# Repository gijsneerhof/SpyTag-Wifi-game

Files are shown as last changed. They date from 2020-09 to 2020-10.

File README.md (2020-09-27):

# WIFI Spy Tag game

Hey there, this is the code used for the WIFI based hide and seek/tag game using ESP8266 devices.
The idea behind the game is that humans go and hide, while two zombies (or agents) start seeking them out.
once a zombie comes in proximity to a human, they turn into zombies themselves. Eventually this game will
be rebranded to a spy type of game, with more powerups and features to play around with.

This project is currently in basic WIP shape, if you would like to burn and test out this project however,
more info can be found here for how to accomplish this: https://github.com/con-f-use/esp82XX-basic

## Hardware

Coming soon!

## Instructions

### Installation

Espressif IDF toolchain

### Usage

The function `user_init()` in `user/user_main.c` will be run first. 

### Building

First do `make erase`, then `make initdefault #init3v3` to set the flash correctly.
Lastly, use `make burn` to upload to the ESP8266 controller over `/dev/ttyUSB0`

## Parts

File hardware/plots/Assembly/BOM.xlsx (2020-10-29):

Designator | Comment | Footprint
C1, C2, C3, C4, C5, C6, C7, C8, C9, C10, C11, C12, C13, C14, C15, C16, C17 | 100nF | C_0603_1608Metric
C18, C19 | 10uF | C_0603_1608Metric
R1, R2, R3, R4, R5 | 10K | R_0603_1608Metric
D1, D2, D3, D4, D5, D6, D7, D8, D9, D10, D11, D12, D13, D14, D15, D16 | WS2812B | LED_WS2812B_PLCC4_5.0x5.0mm_P3.2mm
U1 | ESP-12E | ESP-12E_SMD
SW3 | SW_DPDT_x2 | SW_E-Switch_EG1271_DPDT
SW1 | ZOMBIE | SW_PUSH_6mm

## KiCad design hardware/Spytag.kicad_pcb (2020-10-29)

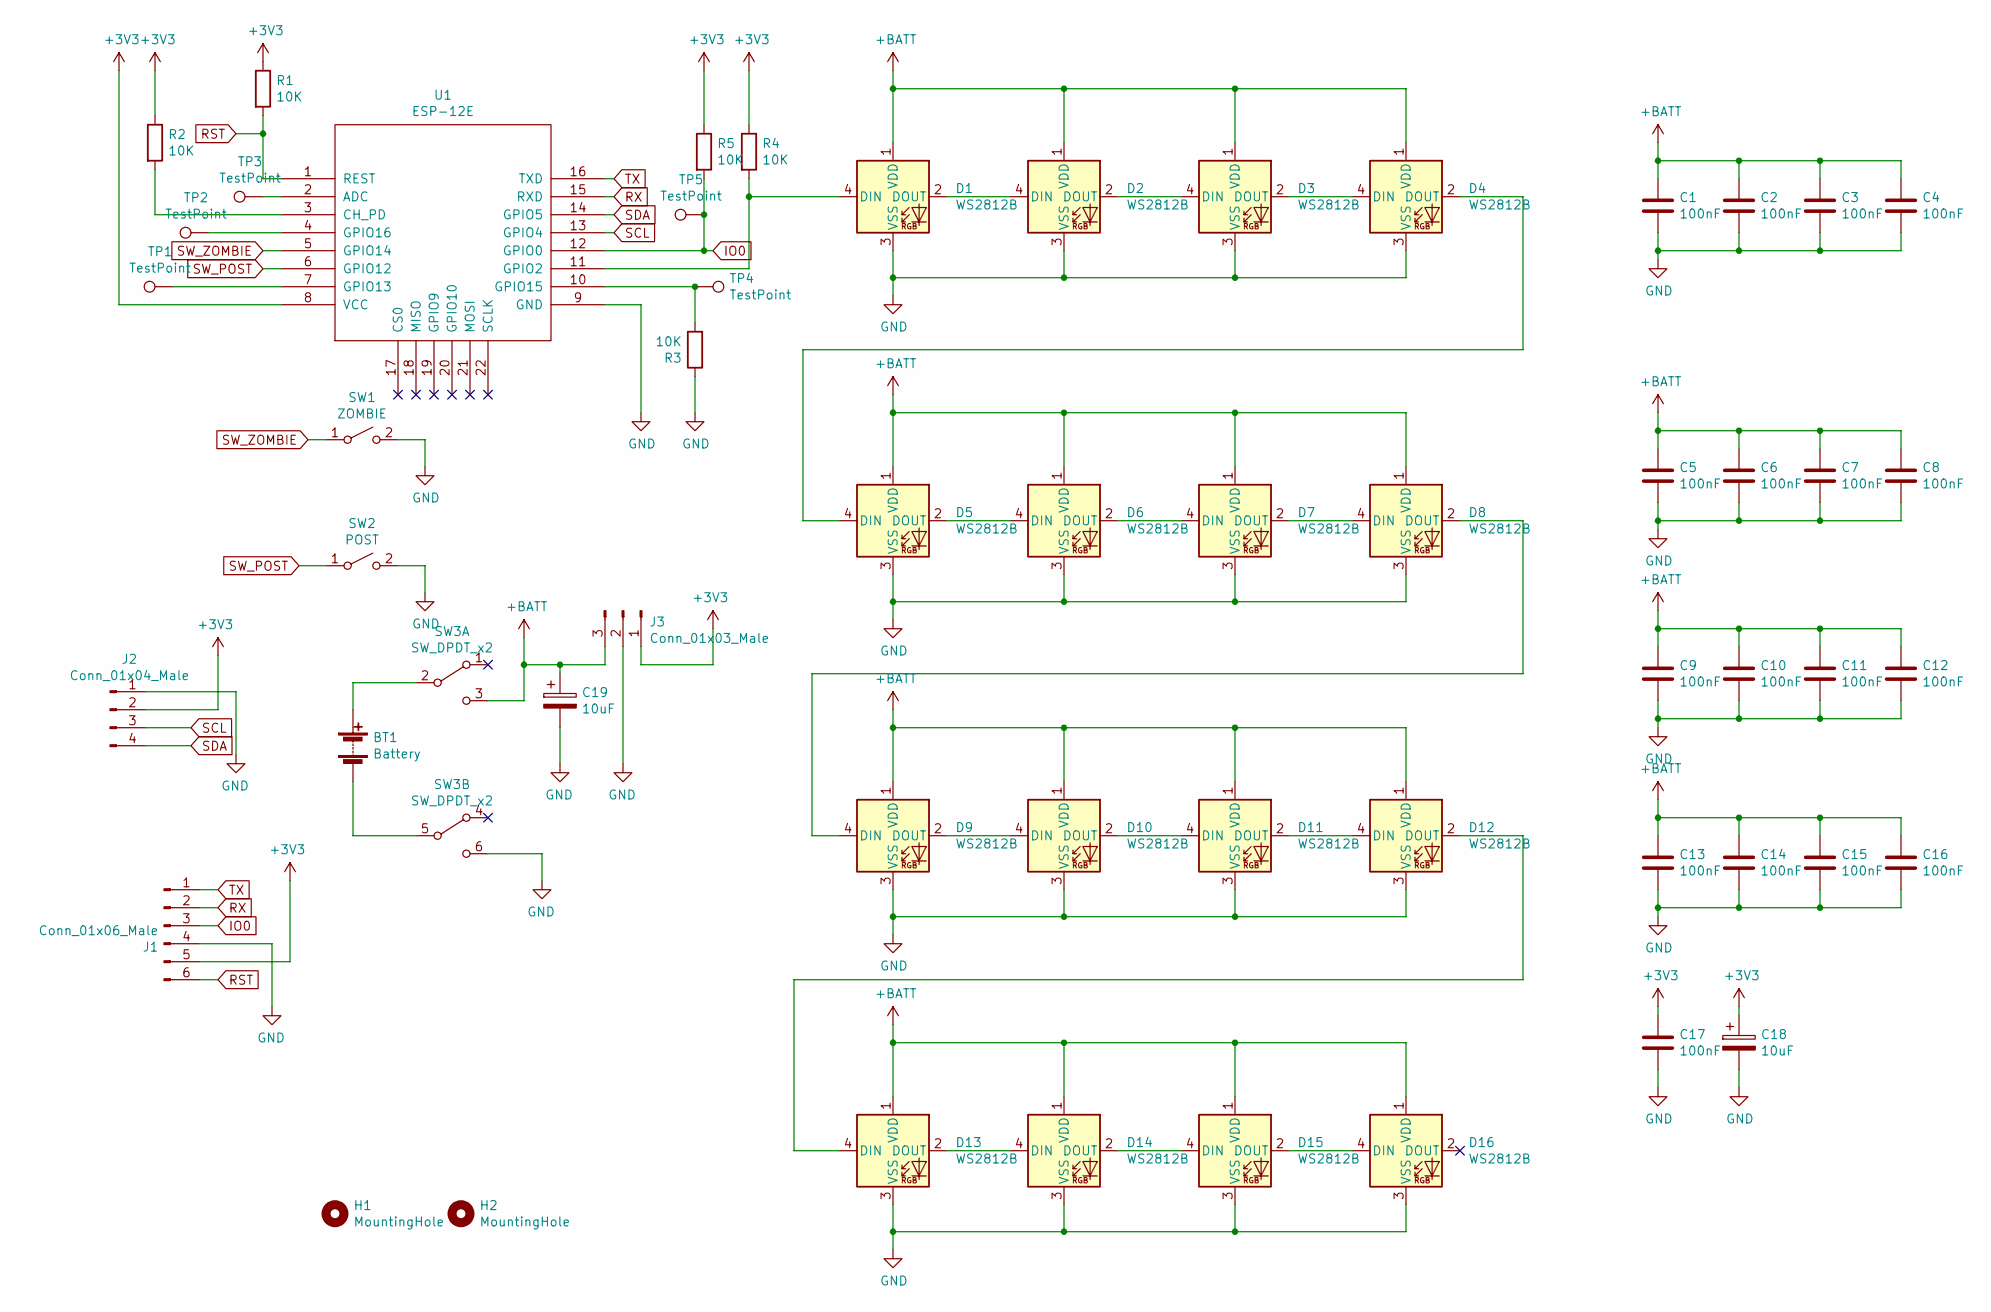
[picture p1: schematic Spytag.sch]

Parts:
BT1: Battery; Generic
C1, C2, C3, C4, C5, C6, C7, C8, C9, C10, C11, C12, C13, C14, C15, C16, C17: 100nF; C_0603_1608Metric
C18, C19: 10uF; C_0603_1608Metric
D1, D2, D3, D4, D5, D6, D7, D8, D9, D10, D11, D12, D13, D14, D15, D16: WS2812B; LED_WS2812B_PLCC4_5.0x5.0mm_P3.2mm
H1, H2: MountingHole; MountingHole_3.2mm_M3
J1: Conn_01x06_Male; PinHeader_1x06_P2.54mm_Vertical
J2: Conn_01x04_Male; PinHeader_1x04_P2.54mm_Vertical
J3: Conn_01x03_Male; PinSocket_1x03_P2.54mm_Vertical
R1, R2, R3, R4, R5: 10K; R_0603_1608Metric
SW1: ZOMBIE; SW_PUSH_6mm
SW2: POST; SW_PUSH_6mm
SW3: SW_DPDT_x2; SW_E-Switch_EG1271_DPDT
TP1, TP2, TP3, TP4, TP5: TestPoint; TestPoint_THTPad_D1.5mm_Drill0.7mm
U1: ESP-12E; ESP-12E_SMD

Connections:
+3V3: C17.1, C18.1, J1.5, J2.2, J3.1, R1.1, R2.1, R4.1, R5.1, U1.8 (VCC)
+BATT: C1.1, C2.1, C3.1, C4.1, C5.1, C6.1, C7.1, C8.1, C9.1, C10.1, C11.1, C12.1, C13.1, C14.1, C15.1, C16.1, C19.1, D1.1 (VDD), D2.1 (VDD), D3.1 (VDD), D4.1 (VDD), D5.1 (VDD), D6.1 (VDD), D7.1 (VDD), D8.1 (VDD), D9.1 (VDD), D10.1 (VDD), D11.1 (VDD), D12.1 (VDD), D13.1 (VDD), D14.1 (VDD), D15.1 (VDD), D16.1 (VDD), J3.3, SW3.3 (C)
GND: C1.2, C2.2, C3.2, C4.2, C5.2, C6.2, C7.2, C8.2, C9.2, C10.2, C11.2, C12.2, C13.2, C14.2, C15.2, C16.2, C17.2, C18.2, C19.2, D1.3 (VSS), D2.3 (VSS), D3.3 (VSS), D4.3 (VSS), D5.3 (VSS), D6.3 (VSS), D7.3 (VSS), D8.3 (VSS), D9.3 (VSS), D10.3 (VSS), D11.3 (VSS), D12.3 (VSS), D13.3 (VSS), D14.3 (VSS), D15.3 (VSS), D16.3 (VSS), J1.4, J2.1, J3.2, R3.1, SW1.2 (B), SW2.2 (B), SW3.6 (C), U1.9 (GND)
IO0: J1.3, R5.2, TP5.1, U1.12 (GPIO0)
unnamed: BT1.1 (+), SW3.2 (B)
unnamed: BT1.2 (-), SW3.5 (B)
unnamed: D1.2 (DOUT), D2.4 (DIN)
unnamed: D1.4 (DIN), R4.2, U1.11 (GPIO2)
unnamed: D2.2 (DOUT), D3.4 (DIN)
unnamed: D3.2 (DOUT), D4.4 (DIN)
unnamed: D4.2 (DOUT), D5.4 (DIN)
unnamed: D5.2 (DOUT), D6.4 (DIN)
unnamed: D6.2 (DOUT), D7.4 (DIN)
unnamed: D7.2 (DOUT), D8.4 (DIN)
unnamed: D8.2 (DOUT), D9.4 (DIN)
unnamed: D10.2 (DOUT), D11.4 (DIN)
unnamed: D9.2 (DOUT), D10.4 (DIN)
unnamed: D11.2 (DOUT), D12.4 (DIN)
unnamed: D12.2 (DOUT), D13.4 (DIN)
unnamed: D13.2 (DOUT), D14.4 (DIN)
unnamed: D14.2 (DOUT), D15.4 (DIN)
unnamed: D15.2 (DOUT), D16.4 (DIN)
unnamed: R2.2, U1.3 (CH_PD)
unnamed: R3.2, TP4.1, U1.10 (GPIO15)
unnamed: TP1.1, U1.7 (GPIO13)
unnamed: TP2.1, U1.4 (GPIO16)
unnamed: TP3.1, U1.2 (ADC)
RST: J1.6, R1.2, U1.1 (REST)
RX: J1.2, U1.15 (RXD)
SCL: J2.3, U1.13 (GPIO4)
SDA: J2.4, U1.14 (GPIO5)
SW_POST: SW2.1 (A), U1.6 (GPIO12)
SW_ZOMBIE: SW1.1 (A), U1.5 (GPIO14)
TX: J1.1, U1.16 (TXD)

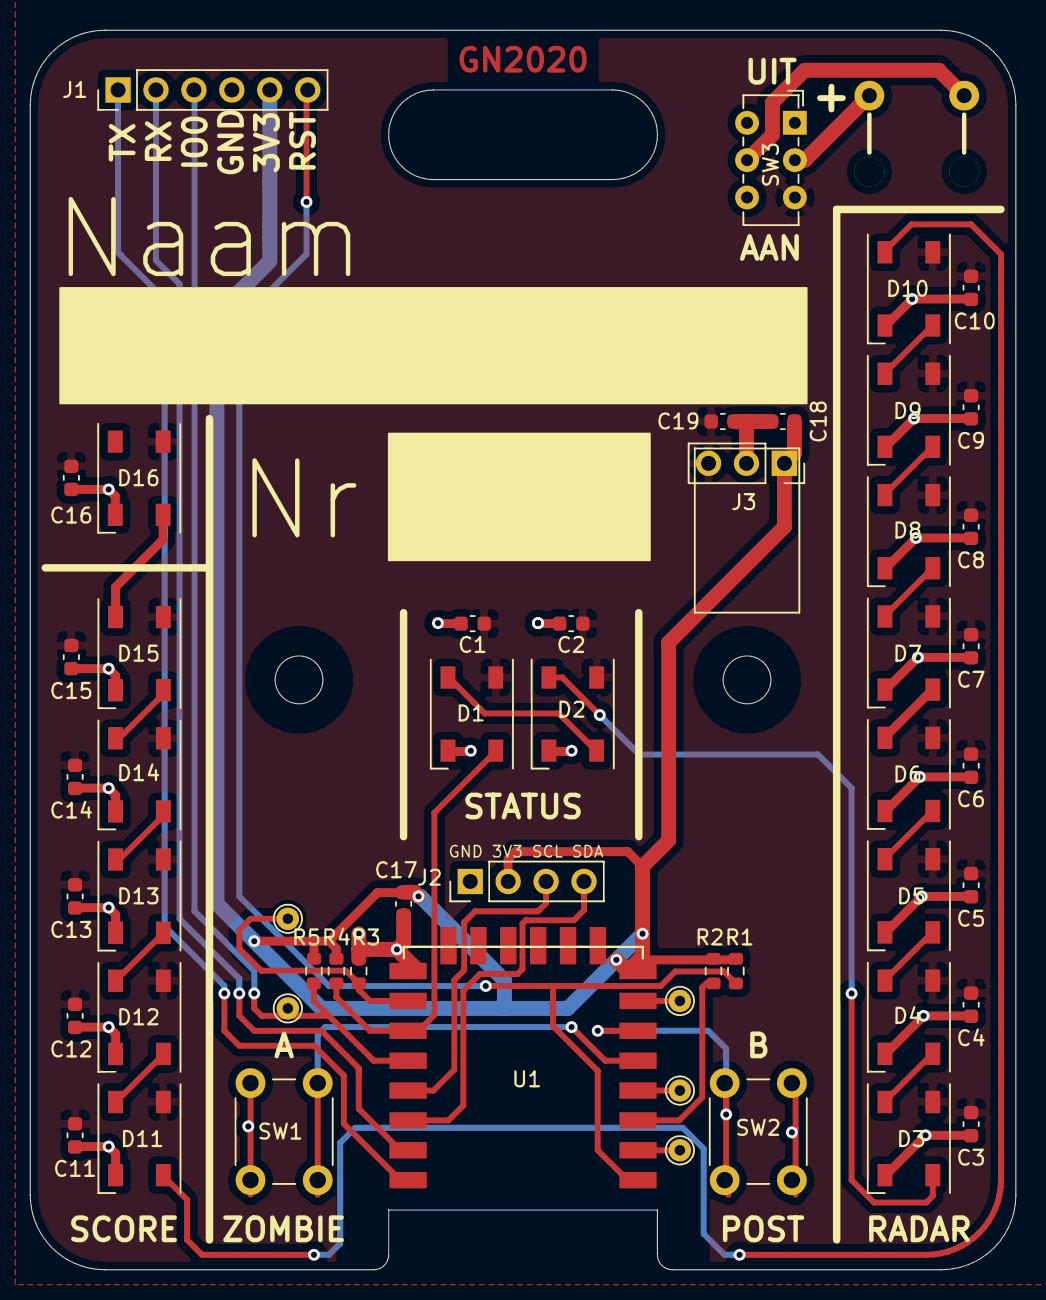
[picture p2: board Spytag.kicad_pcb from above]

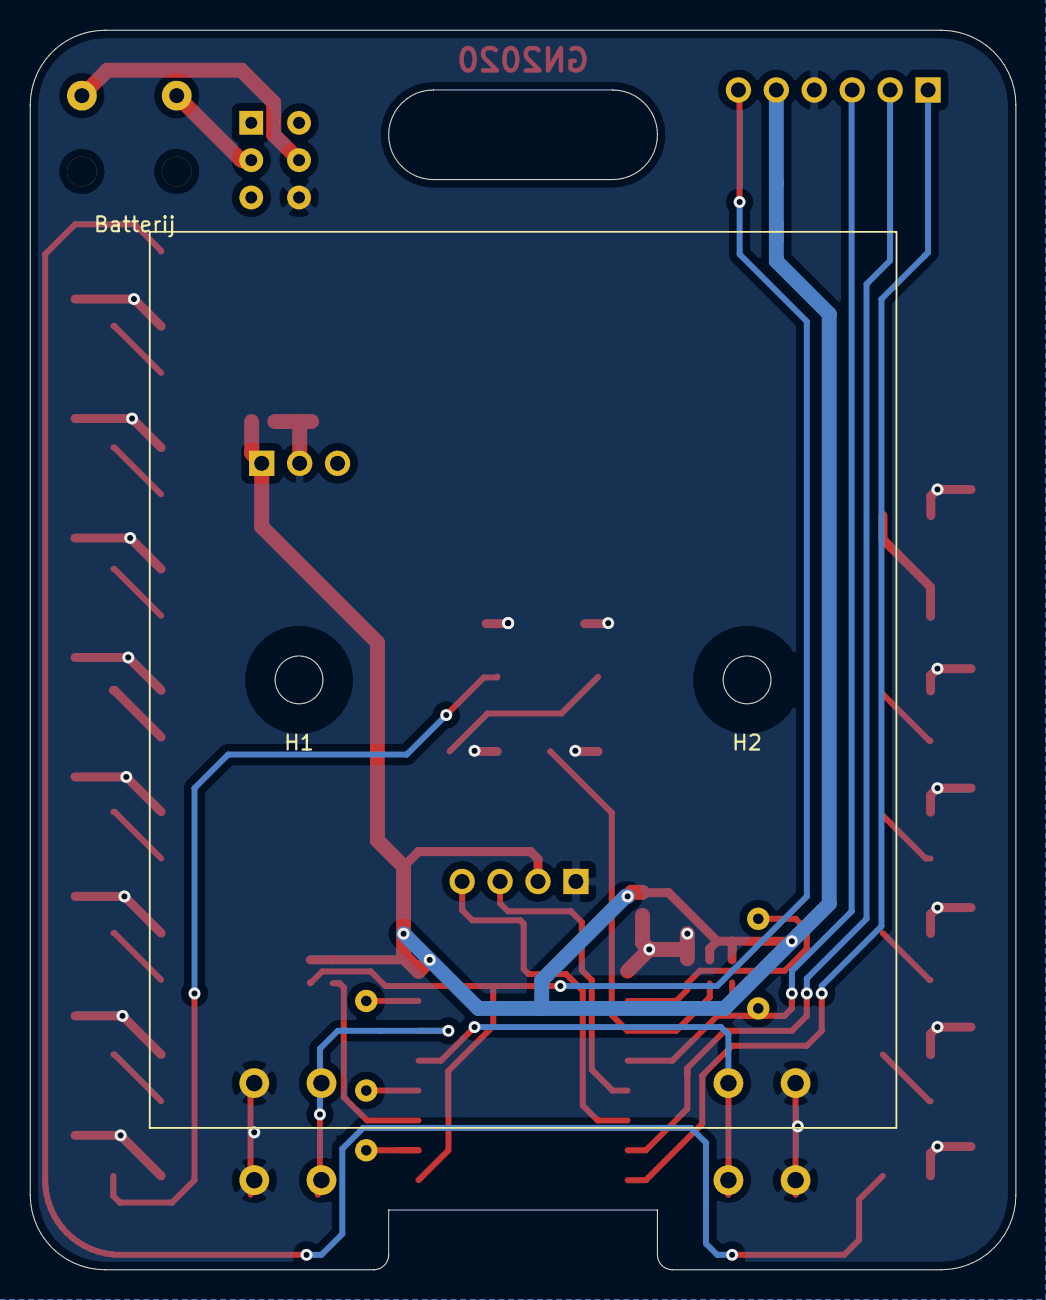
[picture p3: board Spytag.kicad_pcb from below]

Board: 2 copper layers, 66.0 x 83.0 mm, 55 parts (2 on the bottom side), 34 nets.

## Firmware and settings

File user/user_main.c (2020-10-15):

//Copyright 2015 <>< Charles Lohr, see LICENSE file.
//Copyright 2019 <>< Aaron Angert, see LICENSE file.
//Work in Progress

#include "mem.h"
#include "c_types.h"
#include "user_interface.h"
#include "ets_sys.h"
#include "uart.h"
#include "osapi.h"
#include "espconn.h"
#include "esp82xxutil.h"
#include "ws2812.h"
#include "commonservices.h"
#include "vars.h"
#include "gpio.h"
#include "hash.c"
#include <mdns.h>
#include <string.h>
#include <stdio.h>
#include <math.h>

#include "gpio_buttons.h"

#define procTaskPrio 0
#define procTaskInit 1
#define procTaskopts 2

#define procTaskQueueLen 3

#define HUMAN 0
#define ZOMBIE 1
#define SUPERZOMBIE 2
#define ENDGAME 3

#define REDTEAM 4
#define GREENTEAM 5
#define BLUETEAM 6

#define NOTEAM 7

//B button = GPIO 12
//A button = GPIO 4

#define NOBUTTONS 216
#define ABUTTON 220 //post button
#define BBUTTON 218 //zombie button
#define BOTHBUTTONS 222 //endgame buttons

static volatile os_timer_t game_timer;
static volatile os_timer_t end_timer;
static volatile os_timer_t begin_timer;

static volatile os_timer_t game_timer;
static volatile os_timer_t end_timer;

static volatile os_timer_t score_display_timer;

static struct espconn *pUdpServer;
usr_conf_t *UsrCfg = (usr_conf_t *)(SETTINGS.UserData);
//uint8_t last_leds[40*3] = {0};
uint8_t leds[16 * 3] = {0};
// const int N = 300;
hashtable_t *hashtable;

//status of the beacon, and last three recorded rssi values
struct beacon_stat
{
	char *type;
	int rssi[3];
};

int state;
int prev_state;

char states[][32] = {"Human", "Zombie", "SuperZombie", "EndGame", "RedTeam", "GreenTeam", "BlueTeam", "NoTeam"};


int normal_radar[15] = {-300, -90, -85, -80, -75, -70, -65, -62 -60, -58, -55, -52, -50, -46, -42}; 

//int normal_radar[10] = {-100, -95, -90, -85, -80, -75, -70, -65, -60, -55, -50,};

int colors[12 * 3] = {0x00, 0x01, 0x00, //human
					  0x01, 0x00, 0x00, //Zombie
					  0x00, 0x04, 0x00, //Superzombie
					  0x01, 0x00, 0x00, //Dead
					  0x01, 0x00, 0x00, //BlueTeam
					  0x00, 0x01, 0x00, //RedTeam
					  0x00, 0x00, 0x01, //GreenTeam
					  0x01, 0x01, 0x01};//NoTeam

bool end_game = false;

bool button_pressed = false;

//9400
//4800

int light_level = 0x60;

bool show_time = false;
bool show_score = false;

int score = 0;

unsigned long score_cooldown = 0;

int timer_index = 4; //set 30 minutes
int times[8] = {5, 10, 15, 20, 30, 40, 50, 60};

int sensitivity_index = 3; //set  -42
float sensitivities[7] = {-30.0, -34.0, -38.0, -42.0, -46.0, -50.0, -54.0};

int begin_time = 15;

void ICACHE_FLASH_ATTR user_scan(void);


void user_rf_pre_init(void)
{ /*nothing*/
}

char *strcat(char *dest, char *src)
{
	return strcat(dest, src);
}

//Tasks that happen all the time.
os_event_t procTaskQueue[procTaskQueueLen];

//Timer event.
int count_down_time = 16;
static void ICACHE_FLASH_ATTR gameTimer(void *arg)
{
	if (count_down_time <= 1)
	{
		os_timer_disarm(&game_timer);
		end_game = true;
	}
	count_down_time -= 1;
}


//this function sets the begin grace period and counts down. When te timer ticks, this function will be called. 
// When done, user_scan will be called
static void ICACHE_FLASH_ATTR begin_game_func(void *arg)
{
	
	make_radar_full(leds, colors[BLUETEAM*3], colors[BLUETEAM *3+1], colors[BLUETEAM*3+2], begin_time);

	WS2812OutBuffer(leds, sizeof(leds), light_level);
	if (begin_time == 0)
	{
		os_timer_disarm(&begin_timer);
		os_timer_disarm(&game_timer);
		os_timer_setfn(&game_timer, (os_timer_func_t *)gameTimer, NULL);
		os_timer_arm(&game_timer, (times[timer_index] * 60 * 1000) / 16, 1);
		system_os_task(user_scan, procTaskPrio, procTaskQueue, procTaskQueueLen);
		system_os_post(procTaskPrio, 0, 0);
	}
	begin_time -= 1;
}


int end_state = 0;
//this function creates the endstate animation
static void ICACHE_FLASH_ATTR end_game_func(void *arg)
{
	//show score!
	if (end_state % 2 == 0)
	{
		make_lights(leds, 15, colors[state * 3], colors[state * 3 + 1], colors[state * 3 + 2]);
		make_lights(leds, 14, 0, 0, 0);
		make_lights(leds, 13, colors[state * 3], colors[state * 3 + 1], colors[state * 3 + 2]);
		make_lights(leds, 12, 0, 0, 0);
		make_lights(leds, 11, colors[state * 3], colors[state * 3 + 1], colors[state * 3 + 2]);
		make_lights(leds, 10, 0, 0, 0);
		make_lights(leds, 9, colors[state * 3], colors[state * 3 + 1], colors[state * 3 + 2]);
		make_lights(leds, 8, 0, 0, 0);

		make_lights(leds, 7, colors[state * 3], colors[state * 3 + 1], colors[state * 3 + 2]);
		make_lights(leds, 6, 0, 0, 0);
		make_lights(leds, 5, colors[state * 3], colors[state * 3 + 1], colors[state * 3 + 2]);
		make_lights(leds, 4, 0, 0, 0);
		make_lights(leds, 3, colors[state * 3], colors[state * 3 + 1], colors[state * 3 + 2]);
		make_lights(leds, 2, 0, 0, 0);
		make_lights(leds, 1, colors[state * 3], colors[state * 3 + 1], colors[state * 3 + 2]);
		make_lights(leds, 0, 0, 0, 0);
	}
	else
	{
		make_lights(leds, 15, 0, 0, 0);
		make_lights(leds, 14, colors[state * 3], colors[state * 3 + 1], colors[state * 3 + 2]);
		make_lights(leds, 13, 0, 0, 0);
		make_lights(leds, 12, colors[state * 3], colors[state * 3 + 1], colors[state * 3 + 2]);
		make_lights(leds, 11, 0, 0, 0);
		make_lights(leds, 10, colors[state * 3], colors[state * 3 + 1], colors[state * 3 + 2]);
		make_lights(leds, 9, 0, 0, 0);
		make_lights(leds, 8, colors[state * 3], colors[state * 3 + 1], colors[state * 3 + 2]);

		make_lights(leds, 7, 0, 0, 0);
		make_lights(leds, 6, colors[state * 3], colors[state * 3 + 1], colors[state * 3 + 2]);
		make_lights(leds, 5, 0, 0, 0);
		make_lights(leds, 4, colors[state * 3], colors[state * 3 + 1], colors[state * 3 + 2]);
		make_lights(leds, 3, 0, 0, 0);
		make_lights(leds, 2, colors[state * 3], colors[state * 3 + 1], colors[state * 3 + 2]);
		make_lights(leds, 1, 0, 0, 0);
		make_lights(leds, 0, colors[state * 3], colors[state * 3 + 1], colors[state * 3 + 2]);
	}
	int i = 0;
	for(i = 0; i < score;i++){
		make_lights(leds, 14-i, colors[NOTEAM *3], colors[NOTEAM *3 +1], colors[NOTEAM*3 + 2]);
	}

	WS2812OutBuffer(leds, sizeof(leds), light_level);
	end_state = (end_state + 1) % 2;
}

//Called when new packet comes in.
static void ICACHE_FLASH_ATTR
udpserver_recv(void *arg, char *pusrdata, unsigned short len)
{
	struct espconn *pespconn = (struct espconn *)arg;
	uart0_sendStr("X");
}

void ICACHE_FLASH_ATTR charrx(uint8_t c)
{
	//Called from UART.
}

//sets single led (r,g,b)
void make_lights(char light_array[], int light_num, int r, int g, int b)
{
	light_array[light_num * 3] = g;
	light_array[light_num * 3 + 1] = r;
	light_array[light_num * 3 + 2] = b;
}

//callback for wifi scan done
void scan_done(void *arg, STATUS status);

//changes state, edits wifi ssid
void ICACHE_FLASH_ATTR change_state(void)
{
	printf("changing state, state is now %d\n", state);
	prev_state = state;
	struct softap_config softapconfig;
	wifi_softap_get_config(&softapconfig);

	memset(&softapconfig.ssid, 0, sizeof(softapconfig.ssid));
	os_memcpy(&softapconfig.ssid, states[state], sizeof(states[state]));
	softapconfig.channel = 1;

	wifi_softap_set_config_current(&softapconfig);
	wifi_set_opmode(STATIONAP_MODE);
	wifi_softap_set_config_current(&softapconfig);

	make_radar_full(leds, colors[ZOMBIE *3], colors[ZOMBIE *3+1], colors[ZOMBIE*3+2], 16);

}


//called after user_init
void ICACHE_FLASH_ATTR
game_options(void)
{
	system_os_task(game_options, procTaskopts, procTaskQueue, procTaskQueueLen);
	int buttons = GetButtons();

	state = HUMAN;
	if(buttons == BBUTTON){
		state = ZOMBIE;
		change_state();
	}
	else if(buttons == ABUTTON){
		state = NOTEAM;
		change_state();
		make_radar_full(leds, colors[NOTEAM*3], colors[NOTEAM*3 + 1], colors[NOTEAM*3 +2], 16);
		WS2812OutBuffer(leds, sizeof(leds), light_level);
		return;
	}
	else if(buttons == BOTHBUTTONS){
		state = ENDGAME;
		change_state();
		make_radar_full(leds, colors[ENDGAME*3], colors[ENDGAME*3 + 1], colors[ENDGAME*3 +2], 16);
		WS2812OutBuffer(leds, sizeof(leds), light_level);
		return;
	}

	os_timer_disarm(&begin_timer);
	os_timer_setfn(&begin_timer, (os_timer_func_t *)begin_game_func, NULL);
	//begin timer settings, should be 20000
	os_timer_arm(&begin_timer, 2000, 1);
	begin_game_func(1);
	make_radar_full(leds, colors[BLUETEAM *3], colors[BLUETEAM *3+1], colors[BLUETEAM*3+2], begin_time);

	WS2812OutBuffer(leds, sizeof(leds), light_level);
}

//scans for wifi 
void ICACHE_FLASH_ATTR
user_scan(void)
{
	if (end_game)
	{
		os_timer_disarm(&end_timer);
		os_timer_setfn(&end_timer, (os_timer_func_t *)end_game_func, NULL);
		os_timer_arm(&end_timer, 500, 1);
	}
	else
	{
		int buttons = GetButtons();
		//208, no buttons
		//221, A button
		//210, B button
		//223, both buttons

		if (buttons == BBUTTON)
		{
			button_pressed = true;
			show_time = true;
		}

		if (prev_state != state)
		{
			printf("WOOP PREV STATE %d is not state %d changing\n", prev_state, state);
			change_state();
		}

		if (button_pressed && buttons == NOBUTTONS)
		{
			if (show_time)
			{
				show_time = false;
				make_radar_full(leds, 1, 0, 0, 0, 16);
			}
			button_pressed = false;
		}

		struct scan_config config;

		memset(&config, 0, sizeof(config));
		//config.ssid	=	"AI-THINKER_CC47D5";
		config.channel = 1;

		wifi_station_scan(&config, scan_done);
	}
}

//give all leds up to num the color (r,g,b)
void make_radar_full(char leds[], int r, int g, int b, int num)
{
		int a = 0;
		for (a = 0; a < 16; a++)
		{
			if (a <= num)
			{
				make_lights(leds, a, r, g, b);
			}
			else
			{
				make_lights(leds, a, 0, 0, 0);
			}
		}

}

int get_radar_value(int values[], float distance)
{
	int a = 0;
	for (a = 0; a < 14; a++)
	{
		if (distance > values[a])
		{
			continue;
		}
		else
		{

			return a;
		}
	}
	return 14;
}

char macmap[15];

static void ICACHE_FLASH_ATTR end_score_display(void *arg){
	os_timer_disarm(&end_timer);
	show_score = false;
}


void scan_done(void *arg, STATUS status)
{
	system_os_task(user_scan, procTaskPrio, procTaskQueue, procTaskQueueLen);
	uint8 ssid[33];
	char temp[128];
	float closest_zombie = -300.0;

	//This is a human that is not nearby
	float closest_out_human = -300.0;
	float closest_human = -300.0;

	//closest noteam (Scorepoint)
	float closest_out_noteam = -300.0;
	float closest_noteam = -300.0;

	if (status == OK)
	{
		struct bss_info *bss_link = (struct bss_info *)arg;

		while (bss_link != NULL)
		{

			memset(ssid, 0, 33);
			if (strlen(bss_link->ssid) <= 32)
				memcpy(ssid, bss_link->ssid, strlen(bss_link->ssid));
			else
				memcpy(ssid, bss_link->ssid, 32);

			ets_sprintf(macmap, MACSTR, MAC2STR(bss_link->bssid));
			struct beacon_stat *beacon = hasht_get(hashtable, macmap);
			if (!beacon)
			{
				int first_rssi[3] = {bss_link->rssi, bss_link->rssi, bss_link->rssi};

				struct beacon_stat b;
				b.type = ssid;
				b.rssi[0] = bss_link->rssi;
				b.rssi[1] = bss_link->rssi;
				b.rssi[2] = bss_link->rssi;

				ht_set(hashtable, macmap, &b);
				beacon = &b;
			}
			beacon->rssi[0] = beacon->rssi[1];
			beacon->rssi[1] = beacon->rssi[2];
			beacon->rssi[2] = bss_link->rssi;
			//running average of 3 samples
			float average = (beacon->rssi[0] + beacon->rssi[1] + beacon->rssi[2]) / 3.0;

			if (strcmp(ssid, states[ZOMBIE]) == 0 || strcmp(ssid, states[SUPERZOMBIE]) == 0)
			{
				if (average > closest_zombie)
				{
					closest_zombie = average;
				}
			}

			else if (strcmp(ssid, states[HUMAN]) == 0)
			{
				if (average > closest_out_human && average < -50)
				{
					closest_out_human = average;
				}
				if (average > closest_human)
				{
					closest_human = average;
				}
			}
			else if (strcmp(ssid, states[NOTEAM]) == 0)
			{
				if (average > closest_out_noteam && average < -50)
				{
					closest_out_noteam = average;
				}
				if (average > closest_noteam)
				{
					closest_noteam = average;
				}
			}
			else if (strcmp(ssid, states[ENDGAME]) == 0)
			{
				os_timer_disarm(&game_timer);
				end_game = true;
			}

			bss_link = bss_link->next.stqe_next;
		}
	}
	else
	{
		printf("scan	fail	!!!\r\n");
	}
	if (state == HUMAN)
	{

		if (closest_zombie > sensitivities[sensitivity_index])
		{
			state = ZOMBIE;
		}
		if(closest_noteam > sensitivities[sensitivity_index])
		{
			if(!show_score){
				score++;
				show_score = true;
				if(score >=16){
					score = 0;
				}
				//set timer to stop displaying score
					os_timer_disarm(&score_display_timer);
					os_timer_setfn(&score_display_timer, (os_timer_func_t *)end_score_display, NULL);
					os_timer_arm(&score_display_timer, 30000, 0);
			}
		}

		int zombie_num = get_radar_value(normal_radar, closest_zombie);
		make_radar_full(leds, colors[ZOMBIE * 3], colors[ZOMBIE * 3 + 1], colors[ZOMBIE * 3 + 2], zombie_num);

	}
	else if (state == ZOMBIE)
	{

		int human_num = get_radar_value(normal_radar, closest_human);
		make_radar_full(leds, colors[HUMAN * 3], colors[HUMAN * 3 + 1], colors[HUMAN * 3 + 2], human_num);		
	}
	//set colors of own team
	make_lights(leds, 0, colors[state * 3], colors[state * 3 + 1], colors[state * 3 + 2]);
	make_lights(leds, 15, colors[state * 3], colors[state * 3 + 1], colors[state * 3 + 2]);

	if (show_time == true)
	{
		make_radar_full(leds, colors[BLUETEAM * 3], colors[BLUETEAM * 3 + 1], colors[BLUETEAM * 3 + 2], count_down_time);
		WS2812OutBuffer(leds, sizeof(leds), light_level);
	}
	if(show_score == true)
	{
		int i = 0;
		for(i = 0; i < score;i++){
			make_lights(leds, 14-i, colors[NOTEAM *3], colors[NOTEAM *3 +1], colors[NOTEAM*3 + 2]);
		}
	}

	WS2812OutBuffer(leds, sizeof(leds), light_level);

	system_os_post(procTaskPrio, 0, 0);
}



static void ICACHE_FLASH_ATTR procTask(os_event_t *events)
{
}

//THIS DOESN"T WORK
void HandleButtonEvent(uint8_t stat, int btn, int down)
{
	system_os_post(0, 0, 0);
}

void user_init(void)
{

	state = 0;
	prev_state = 0;
	printf("start state, state is now %d\n", state);
	printf("SDK	version:%s\n", system_get_sdk_version());
	printf("ESP8266	chip	ID:0x%x\n", system_get_chip_id());

	uart_init(BIT_RATE_115200, BIT_RATE_115200);
	uart0_sendStr("\r\nesp82XX Web-GUI\r\n" VERSSTR "\b");

	char nameo[32] = "Human";
	struct softap_config softapconfig;
	wifi_softap_get_config(&softapconfig);

	memset(&softapconfig.ssid, 0, sizeof(softapconfig.ssid));

	os_memcpy(&softapconfig.ssid, nameo, sizeof(nameo));
	softapconfig.channel = 1;

	wifi_softap_set_config_current(&softapconfig);
	wifi_set_opmode(STATIONAP_MODE);
	wifi_softap_set_config_current(&softapconfig);

	SetupGPIO();

	int buttons = GetButtons();

	hashtable = hasht_create(300);
	// wifi scan has to after system init done.

	gpio_init();
	PIN_FUNC_SELECT(PERIPHS_IO_MUX_GPIO2_U, FUNC_GPIO2);
	GPIO_OUTPUT_SET(GPIO_ID_PIN(2), 0);
	printf("ESP8266	chip ID:0x%x\n", system_get_chip_id());
	printf("makeleds\n");
	make_radar_full(leds, 0,0,0,16);
	printf("made leds\n");

	system_init_done_cb(game_options);
	//Timer example
	//os_timer_disarm(&some_timer);
	//os_timer_setfn(&some_timer, (os_timer_func_t *)myTimer, NULL);
	//os_timer_arm(&some_timer, 10000, 0);


}

//There is no code in this project that will cause reboots if interrupts are disabled.
void EnterCritical() {}

void ExitCritical() {}

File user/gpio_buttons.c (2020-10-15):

#include "gpio_buttons.h"
#include "user_interface.h"
#include "c_types.h"
#include <gpio.h>
#include <ets_sys.h>
#include <esp82xxutil.h>

void gpio_pin_intr_state_set(uint32 i, GPIO_INT_TYPE intr_state);

volatile uint8_t LastGPIOState;

//static const uint8_t GPID[] = { 0, 12 };
static const uint8_t GPID[] = {0, 12, 5};
static const uint8_t Func[] = {FUNC_GPIO0, FUNC_GPIO12, FUNC_GPIO5 };
static const int  Periphs[] = {PERIPHS_IO_MUX_GPIO0_U, PERIPHS_IO_MUX_MTDI_U, PERIPHS_IO_MUX_GPIO5_U };





void ICACHE_FLASH_ATTR SetupGPIO()
{
	printf( "SETTING UP GPIO\n" );

	int i;
	ETS_GPIO_INTR_DISABLE(); // Disable gpio interrupts

	for( i = 0; i < 3; i++ )
	{
		PIN_FUNC_SELECT(Periphs[i], Func[i]);
		PIN_DIR_INPUT = 1<<GPID[i];
		PIN_PULLUP_EN(Periphs[i]);
		printf("set GPIO %d as input\n", GPID[i]);
	}
	LastGPIOState = GetButtons();
 	printf( "Setup GPIO Complete\n" );
}


uint8_t GetButtons()
{
	uint8_t ret = 0;
	int i;
	uint32_t pin = PIN_IN;
	int mask = 1;
	for( i = 0; i < 3; i++ )
	{
		ret |= (pin & (1<<GPID[i]))?mask:0;
		printf("[ret %d, i %d, mask %d]", ret, i , mask)
		mask <<= 1;
	}
	ret ^= ~32; //GPIO15's logic is inverted.  Don't flip it but flip everything else.
	printf("got button %d\n", ret);
	return ret;
}

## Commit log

2020-09-06 changed LED code
2020-09-06 commented not working code
    [ws2812.c]
2020-09-06 Added printline
2020-09-06 make begin game timer working
2020-09-07 changed LED workings and made them brighter
2020-09-07 fixed grace period LED
    [user_main.c]
2020-09-08 updated LEDs on init
2020-09-23 decreased grace period time added color switch in grace period (zombie /human)
2020-09-27 fix to radar balance
    [user_main.c]
2020-09-27 removed printing
2020-10-05 Update gpio_buttons.c
    change button a
2020-10-05 Revert "Update gpio_buttons.c"
    This reverts commit 5f7945b347dd6e14e88b455876220a88865fb2e6.
    [gpio_buttons.c]
2020-10-05 Revert "Update gpio_buttons.c"
    This reverts commit a8e8c395f52333198364e11942960c95ad1f11ff.
    [gpio_buttons.c]
2020-10-15 Update gpio_buttons.c
    changed buttons to check
2020-10-15 Update gpio_buttons.c
    fixed typos
    [gpio_buttons.c]
2020-10-15 Revert "Update gpio_buttons.c"
    This reverts commit e5e5ab5289cdb038afbc0b2c327998b03ec83b32.
    [gpio_buttons.c]
2020-10-15 Revert "Update gpio_buttons.c"
    This reverts commit 4178669b4f6e888c402663ea6bbbc4730a29600e.
    [gpio_buttons.c]
2020-10-15 Revert "Update gpio_buttons.c"
    This reverts commit 261d45f54d4ae01195b26ec9ca1ff1db794dddcb.
    [gpio_buttons.c]
2020-10-15 Revert "Update gpio_buttons.c"
    This reverts commit 855671d98141f3110729214135b2724edba1bcfd.
    [gpio_buttons.c]
2020-10-29 added kicad design
    [BOM.xlsx, SpyTag-Wifi-game.fz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]
